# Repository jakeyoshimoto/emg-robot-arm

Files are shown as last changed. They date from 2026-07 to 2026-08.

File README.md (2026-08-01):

# emg-robot-arm

A project to build a 6-DOF robotic arm that uses a tripod-mounted
camera to visually locate a ball on a table and autonomously moves to
grab it. Earlier plans to control the gripper via EMG (muscle-signal)
gestures have been dropped in favor of this camera-only approach.

```
emg-robot-arm/
├── README.md
├── requirements.txt
├── arm/           # PlatformIO firmware for the arm's stepper motors
├── CAD/           # CAD/STL files for the arm and gripper
├── vision/        # camera calibration, ball detection, hand tracking
├── integration/   # wires vision output to arm serial commands
├── docs/          # gantt chart / deadlines
└── datasheets/    # reference PDFs
```

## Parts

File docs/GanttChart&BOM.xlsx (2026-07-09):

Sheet: Gantt Chart
EMG-Controlled Robotic Hand & 7-DOF Robotic Arm — 30-Day Project Gantt Chart
Day-by-day schedule, Day 1–Day 30. All parts are pre-purchased and assumed to arrive by Day 7; Gray columns are scheduled rest days (2 every 7). Yellow cells are hard deadlines for a specific component.
 | Hand Subsystem
 | Arm Subsystem
 | Integration
 | Concept/Shared
 | Hard Deadline
 | Rest Day
ID | Task | Start Day | End Day | Duration (days) | 1 | 2 | 3 | 4 | 5 | 6 | 7 | 8 | 9 | 10 | 11 | 12 | 13 | 14 | 15 | 16 | 17 | 18 | 19 | 20 | 21 | 22 | 23 | 24 | 25 | 26 | 27 | 28 | 29 | 30
1.1/2.1 | Requirements + kickoff (gesture set, joint layout, payload target) | 1 | 1 | 1
2.3 | Arm: vision architecture decision | 1 | 1 | 1
1.4 | Hand CAD: fingers, palm, tendon channels | 1 | 2 | 2
1.5 | Hand CAD: forearm sleeve + wrist joint | 2 | 2 | 1
2.4 | Arm CAD: base, 7 links, motor mounts, interface plate | 1 | 4 | 4
2.4a | Cycloidal drive CAD: housing + disc (joints 1-3) | 3 | 4 | 2
DL1 | HARD DEADLINE: Hand + Arm CAD files finalized, ready to print | 4 | 4 | 1
1.6 | Print hand parts (fingers/palm) - first article | 3 | 4 | 2
1.7 | Print hand parts - reprint pass if needed | 5 | 5 | 1
2.5 | Print arm base + 3 proximal links | 4 | 5 | 2
2.5a | Print cycloidal drive housings + discs (3 joints) | 5 | 5 | 1
1.12pre | EMG firmware skeleton: acquisition + filtering (dev against simulated signal) | 1 | 3 | 3
1.13pre | Gesture classification logic (dev against recorded/simulated EMG data) | 3 | 5 | 3
2.11 | Forward/inverse kinematics solver (math only, no hardware needed) | 1 | 3 | 3
2.12 | Trajectory/motion planning logic | 3 | 5 | 3
2.16pre | Path planning algorithm dev (against simulated/sample scenes) | 4 | 5 | 2
DL2 | HARD DEADLINE: All purchased parts received and inventoried | 8 | 8 | 1
2.6 | Print remaining 4 distal links + end-effector plate | 8 | 8 | 1
2.7 | Reprint pass: warped/failed structural & cycloidal parts | 9 | 9 | 1
1.10 | Bench-test EMG sensor module (hardware now in hand) | 8 | 8 | 1
1.8 | Hand mechanical assembly (tendons, bearings, pins) | 9 | 9 | 1
1.9 | Mount servos in forearm housing | 10 | 10 | 1
1.11 | Electrode placement + skin-contact validation | 10 | 10 | 1
1.12 | EMG firmware: integrate with real sensor signal | 11 | 11 | 1
2.9 | Wire 2x CNC shield/A4988 kits + power distribution | 9 | 10 | 2
2.8 | Arm mechanical assembly incl. cycloidal stage install | 11 | 12 | 2
2.10 | Motion controller firmware: homing, position control (real hardware) | 12 | 12 | 1
DL3 | HARD DEADLINE: Hand fully assembled, Arm fully assembled | 12 | 12 | 1
1.14 | EMG calibration routine + UI | 15 | 15 | 1
1.15 | EMG recalibration iterations (electrode drift, cross-talk) | 15 | 16 | 2
1.16 | Integrate classifier output -> servo mapping | 16 | 16 | 1
1.17 | Grasp tuning (grip force, finger sequencing) | 17 | 18 | 2
DL4 | HARD DEADLINE: Hand catches and holds ball standalone | 18 | 18 | 1
2.13 | Camera calibration, workspace mapping | 15 | 15 | 1
2.14 | Target (ball) detection via OpenCV/MediaPipe | 16 | 17 | 2
2.15 | Obstacle detection + occupancy mapping | 17 | 17 | 1
2.16 | Path planning algorithm with obstacle avoidance (real hardware) | 18 | 19 | 2
2.18 | Integrate vision -> planner -> motion control loop | 18 | 19 | 2
2.18a | Measure cycloidal joint torque vs bare gearbox | 19 | 19 | 1
2.19 | Accuracy + obstacle avoidance tuning | 19 | 19 | 1
DL5 | HARD DEADLINE: Arm reaches target + avoids obstacles standalone | 19 | 19 | 1
3.1 | Mechanical integration: mount hand on arm | 22 | 22 | 1
3.2 | Electrical integration: consolidate harness/power | 22 | 23 | 2
3.3 | Software integration: unify control loop | 23 | 23 | 1
DL6 | HARD DEADLINE: Combined hand+arm software pipeline runs end-to-end (no ball) | 23 | 23 | 1
3.4 | End-to-end dry run (no ball) | 24 | 24 | 1
3.5 | Integration debugging pass | 24 | 25 | 2
DL7 | HARD DEADLINE: Integrated system ready for live-ball trials | 25 | 25 | 1
3.7a | Live trials: full autonomous grasp-and-relocate (round 1) | 26 | 26 | 1
3.7b | Live trials: full autonomous grasp-and-relocate (round 2) | 29 | 29 | 1
3.8 | Rehearsal + contingency prep for final demo | 29 | 29 | 1
DL8 | HARD DEADLINE: Final demonstration | 30 | 30 | 1
3.10 | FINAL DEMONSTRATION | 30 | 30 | 1

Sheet: BOM
EMG-Controlled Robotic Hand
Item | Qty | Cost | Total Cost | Purpose | Source | Progress
EMG Module | 1 | $18.87 | $18.87 | Muscle Contraction Detection | Amazon (https://www.amazon.com/gp/product/B0DQXTVHVX/ref=ox_sc_act_title_1?smid=A1FTIC6G3UW3VA&psc=1) | Not Purchased
EMG Patches 100x | 1 | $17.05 | $17.05 | EMG Replacement Patches | Amazon (https://a.co/d/07yVu8p0) | Not Purchased
MG90S Metal Gear 180 degree Micro Servo 8x | 1 | $18.99 | $18.99 | Finger Articulation Closed | Amazon (https://a.co/d/0gxD0TTA) | Not Purchased
Fishing Line | 1 | $0.00 | $0.00 | Finger Ligaments | Home | Not Purchased
Torsion Spring 10x | 1 | $5.72 | $5.72 | Finger Articulation Open | Amazon (https://a.co/d/030Xd55T) | Not Purchased
Screws, nuts, bolts, misc | 1 | $0.00 | $0.00 | Fixture and Assembly | Home | Not Purchased
PLA filament | 1 | $0.00 | $0.00 | Raw Material | Home | Not Purchased
uxcell 688ZZ Ball Bearing 8x16x5mm (20-pack) | 1 | $8.99 | $8.99 | Finger Joint Bearings | Amazon (https://www.amazon.com/uxcell-Bearing-Shielded-2080088-Bearings/dp/B07FW2YKL8) | Not Purchased
Hand Subtotal |  | $69.62
7-DOF Intelligent Robotic Arm
Item | Qty | Cost |  | Purpose | Source | Progress
FREENOVE Basic Starter Kit for ESP32-S3 | 2 | $25.56 | $51.12 | Microcontroller for Motor Control + Vision Interface | Amazon (https://a.co/d/04XNQ9UA) | Not Purchased
10Pack Nema 17 Stepper Motor | 1 | $66.14 | $66.14 | Arm Joint Actuation | Amazon (https://a.co/d/076g9hVv) | Not Purchased
ACEIRMC 3D Printer CNC Shield V3 + A4988 Driver | 2 | $9.99 | $19.98 | Motor Driver (1 packs = 5 drivers) | Amazon (https://a.co/d/08AV3k6i) | Not Purchased
NICE-POWER DC Power Supply Variable 30V 10A | 1 | $44.99 | $44.99 | Driver/Motor Power Supply | Amazon (https://www.amazon.com/NICE-POWER-Adjustable-Switching-Regulated-Adjustments/dp/B0CDW12H3X) | Not Purchased
HiLetgo KW12-3 Micro Limit Switch (10-Pack) | 1 | $7.99 | $7.99 | Joint Homing Reference (7 needed) | Amazon (https://www.amazon.com/HiLetgo-KW12-3-Roller-Switch-Normally/dp/B07X142VGC) | Not Purchased
uxcell 10 Pcs 6807ZZ Deep Groove Ball Bearings, 35 x 47 x 7mm | 1 | $14.79 | $14.79 | Ball bearing output side | Amazon (https://a.co/d/01JxlTTg) | Not Purchased
20Pcs 6703-ZZ Ball Bearing, 17x23x4mm | 1 | $14.94 | $14.94 | Ball bearing input side | Amazon (https://a.co/d/0c2jdGzu) | Not Purchased
uxcell 22mm Latching Emergency Stop Button (NC) | 1 | $8.99 | $8.99 | Manual Motor Power Cutoff | Amazon (https://www.amazon.com/uxcell-Mounting-Latching-Emergency-Button/dp/B07FRYTH3Z) | Not Purchased
ELEGOO 120pc Dupont Jumper Wire Kit | 1 | $6.99 | $6.99 | ESP32 Prototyping + Sensor Wiring | Amazon (https://www.amazon.com/Elegoo-EL-CP-004-Multicolored-Breadboard-arduino/dp/B01EV70C78) | Not Purchased
Screws, nuts, bolts, misc | 1 | $0.00 | $0.00 | Fixture and Assembly | Home | Not Purchased
PLA filament | 1 | $0.00 | $0.00 | Raw Material | Home | Not Purchased
Zip Ties + Electrical Tape | 1 | $8.00 | $8.00 | Cable Management | Home Depot | Not Purchased
Arm Subtotal |  |  | $243.93
Grand Total |  |  | $243.93

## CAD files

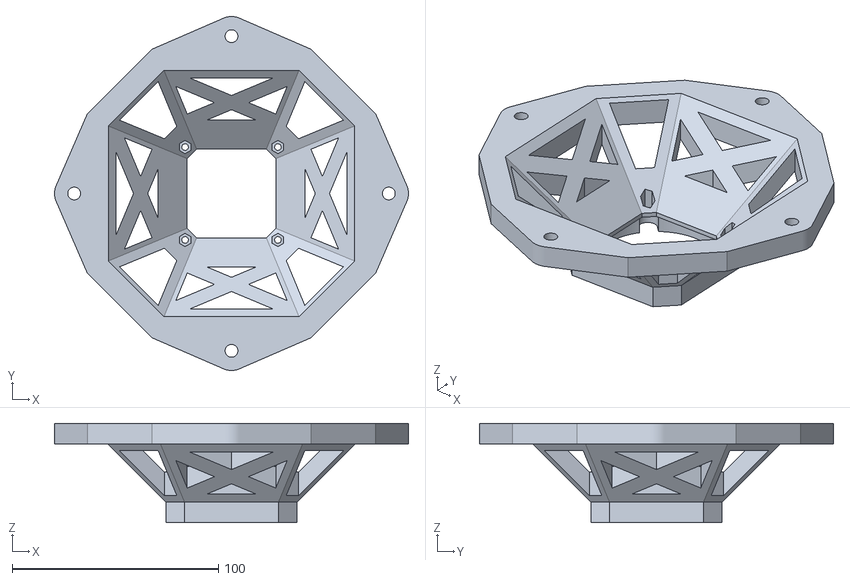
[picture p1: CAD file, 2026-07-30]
CAD/6DoF Arm/Base in mm.stl
171.4 x 171.4 x 48.1

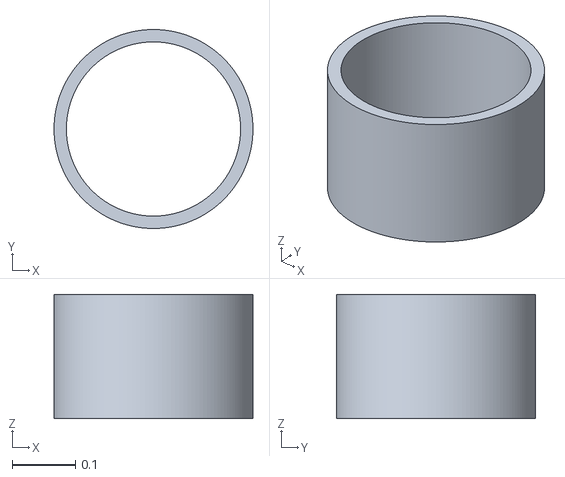
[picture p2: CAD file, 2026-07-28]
CAD/Cycloidal Drive Gearbox/CDG V2 - spacer v2.stl
0.315 x 0.315 x 0.197

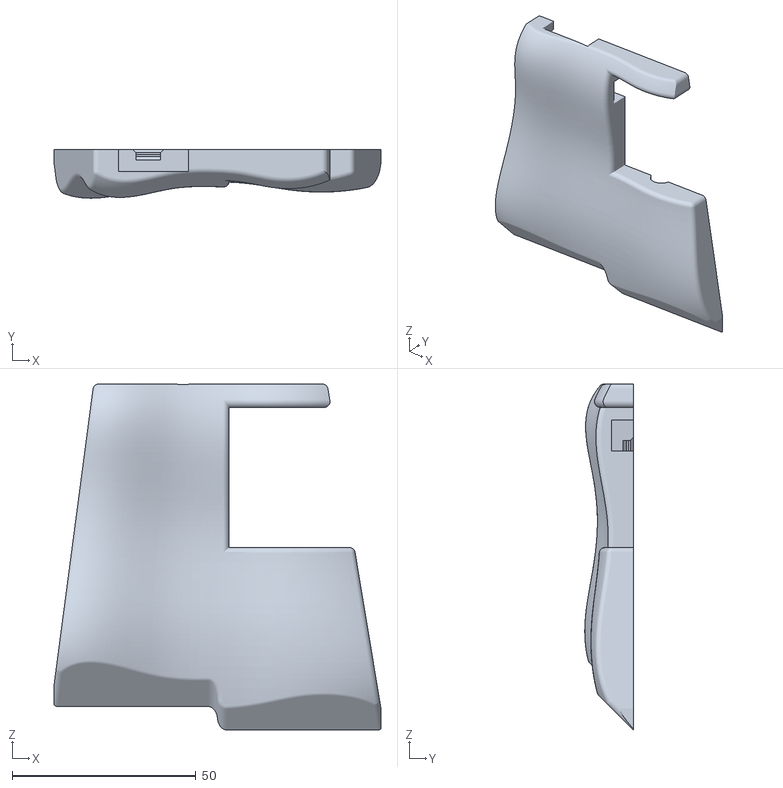
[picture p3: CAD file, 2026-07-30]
CAD/Hand/palm bot no thumb v9 real.stl
88.9 x 13.2 x 94.1

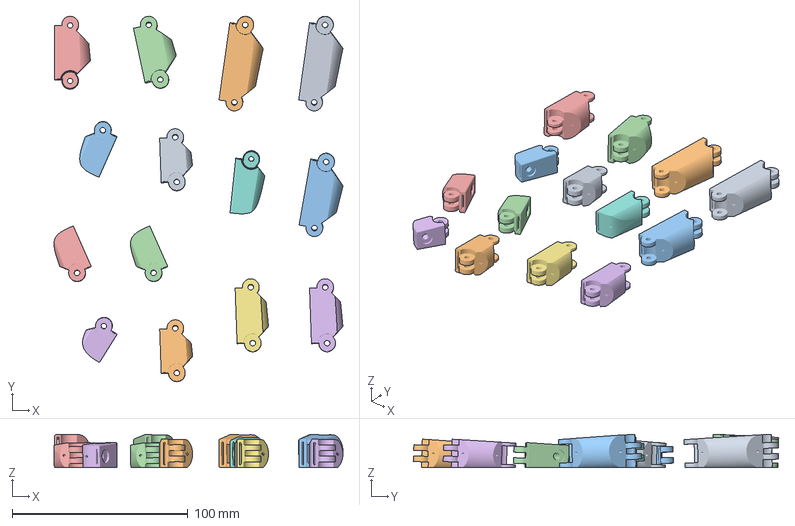
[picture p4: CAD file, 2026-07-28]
CAD/v6/robot_hand_fingers_v7.3mf
164.4 x 208.0 x 19.0 mm
Middle_Ring mcp v6.STL x 2
Index mcp v6.STL
Pinky mcp v6.STL
thumb base v1.STL
Middle_Ring pip v6.STL x 2
thumb tip v1.STL
Pinky pip v6.STL
Index pip v6.STL
Index dip v6.STL
Middle_Ring dip v6.STL x 2
Pinky dip v6.STL

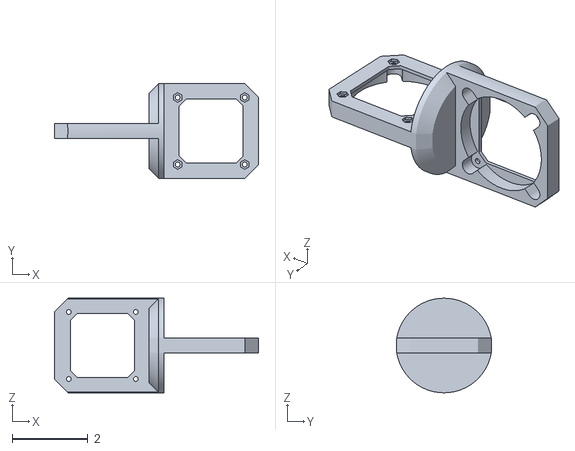
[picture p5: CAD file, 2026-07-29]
CAD/6DoF Arm/Joint 3-4 Mount.stl
5.39 x 2.50 x 2.50

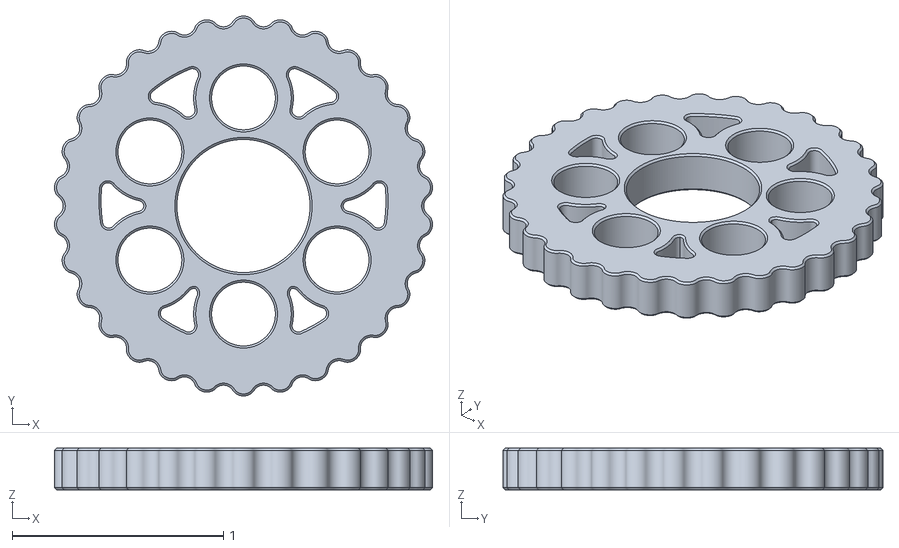
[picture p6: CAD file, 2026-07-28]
CAD/Cycloidal Drive Gearbox/CDG V2 - Cycloidal Disk B.stl
1.79 x 1.80 x 0.197

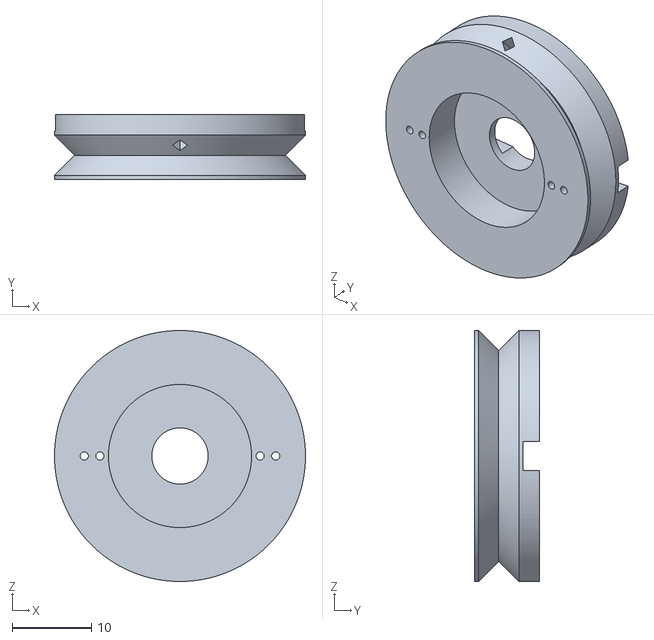
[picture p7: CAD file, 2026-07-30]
CAD/Hand/Pulley v4.stl
31.8 x 8.25 x 31.8

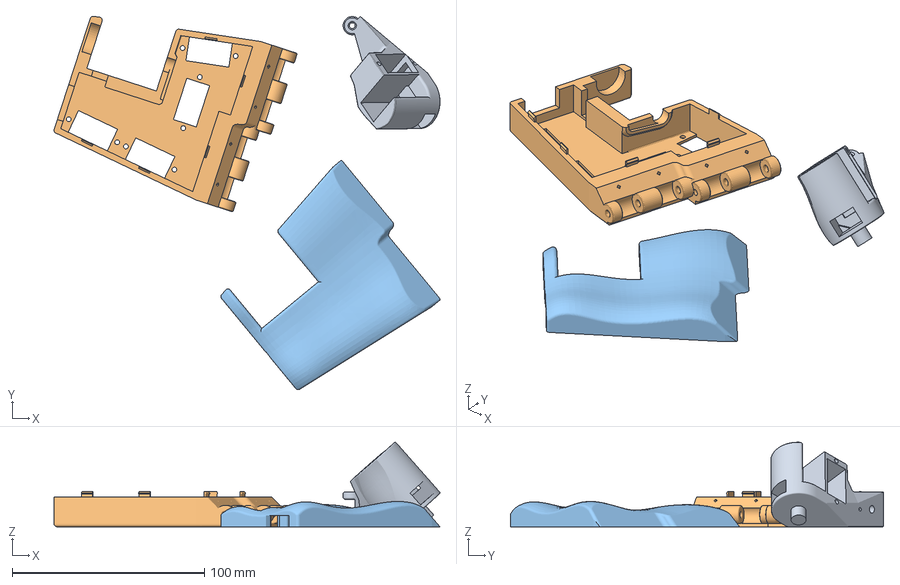
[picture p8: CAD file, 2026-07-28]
CAD/v6/robot_hand_palm_v7.3mf
201.0 x 194.5 x 44.0 mm
palm thumb v6.stl
palm top no thumb v7.STL
palm bot no thumb v7.STL

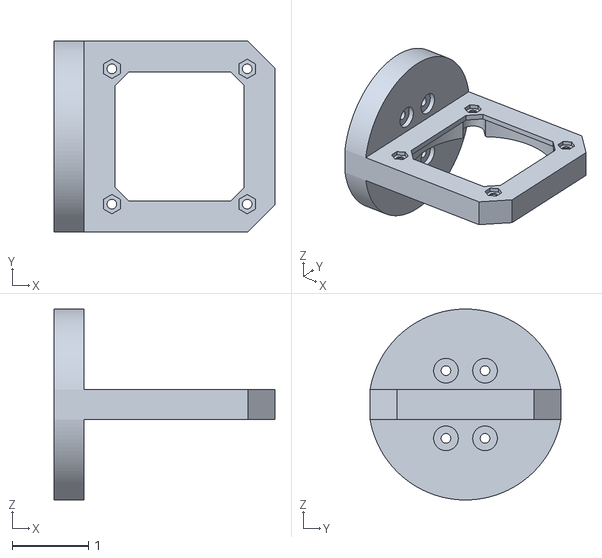
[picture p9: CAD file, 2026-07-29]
CAD/6DoF Arm/Joint 4-5 Mount.stl
2.89 x 2.50 x 2.50

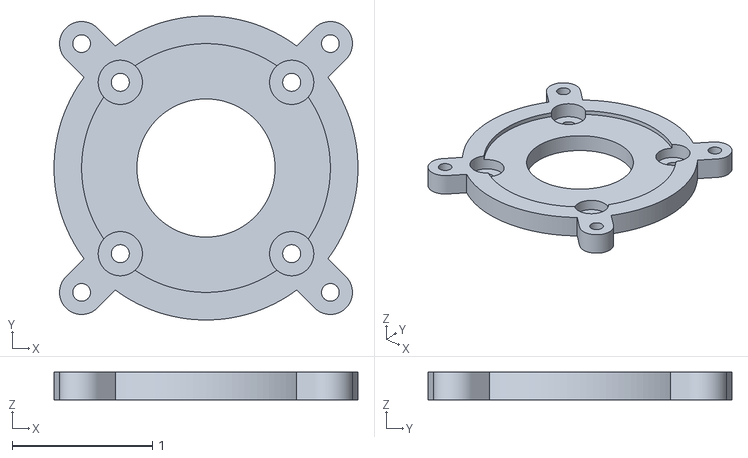
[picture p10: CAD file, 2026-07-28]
CAD/Cycloidal Drive Gearbox/CDG V2 - Motor Plate.stl
2.17 x 2.17 x 0.197

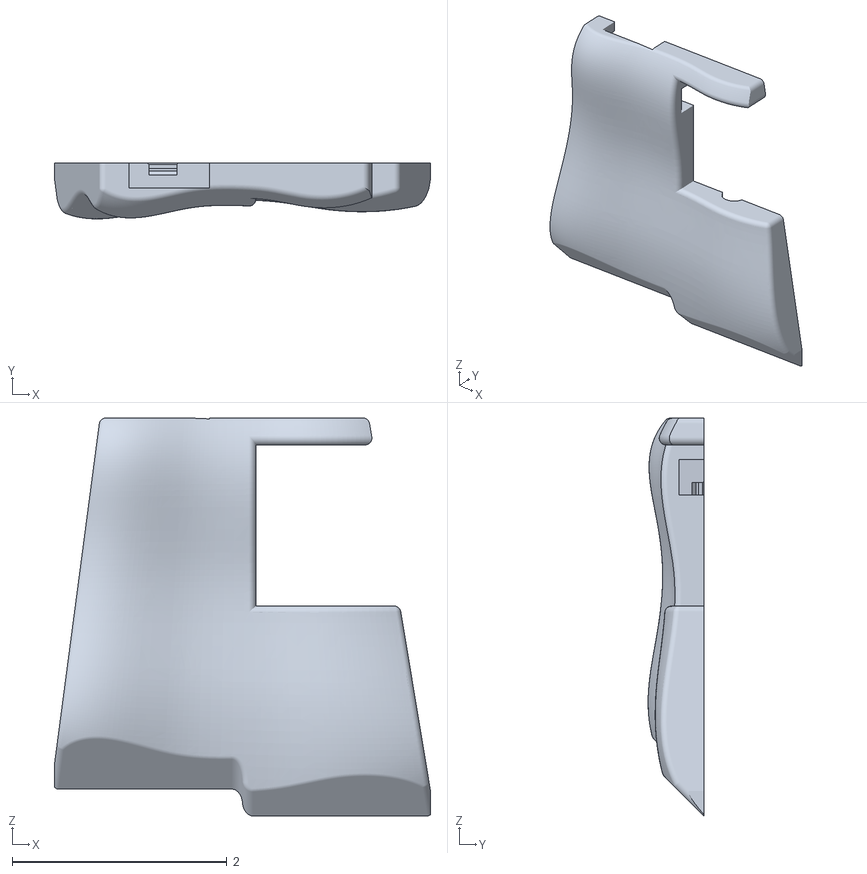
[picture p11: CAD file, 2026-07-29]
CAD/Hand/Palm Bot No Thumb v8.stl
3.50 x 0.519 x 3.70

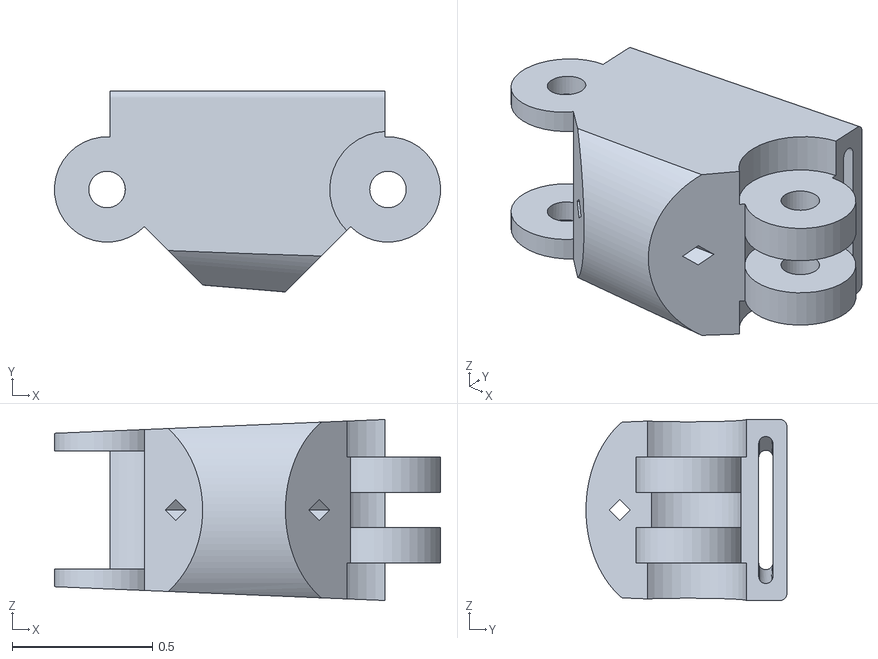
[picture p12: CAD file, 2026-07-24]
CAD/v6/Pinky pip v6.STL
1.37 x 0.716 x 0.645

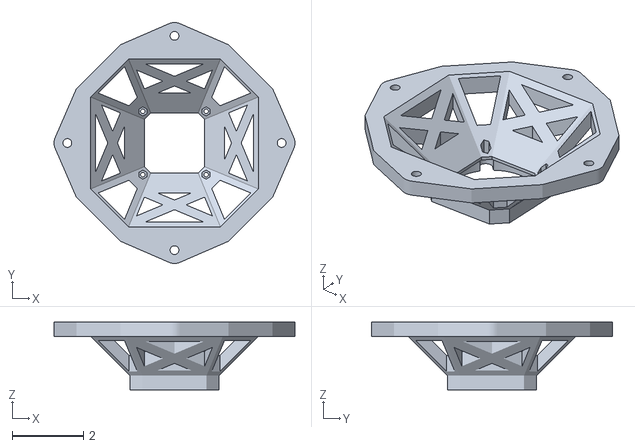
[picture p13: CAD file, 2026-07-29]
CAD/6DoF Arm/Base Mount.stl
6.75 x 6.75 x 1.89

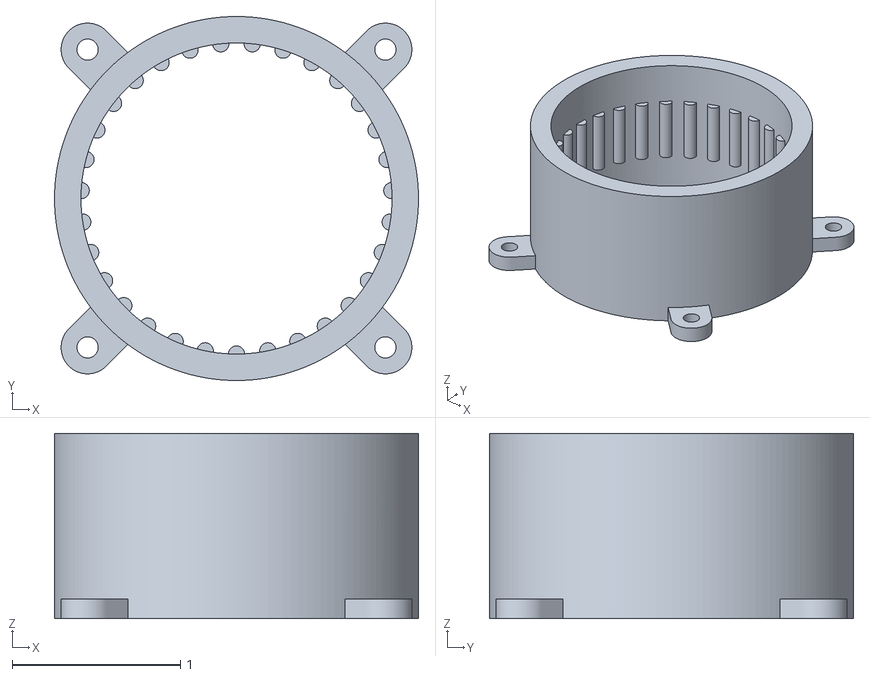
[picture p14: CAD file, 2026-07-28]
CAD/Cycloidal Drive Gearbox/CDG V2 - Ring Gear.stl
2.17 x 2.17 x 1.10

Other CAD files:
CAD/v6/Index mcp v6.STL
CAD/6DoF Arm/Arm 1.stl
CAD/Cycloidal Drive Gearbox/CDG V2 - Bottom Plate.stl
CAD/v6/Middle_Ring dip v6.STL
CAD/6DoF Arm/Arm 2.stl
CAD/6DoF Arm/Hand Joint Mount.stl
CAD/Cycloidal Drive Gearbox/CDG V2 - Cycloidal Disk T.stl
CAD/Cycloidal Drive Gearbox/CDG V2 - Input Shaft T.stl
CAD/Cycloidal Drive Gearbox/CDG V2 - Top Plate.stl
CAD/v5/index dip final (2).STL
CAD/v5/index mcp final (2).STL
CAD/v5/index pip final (2).STL
CAD/v5/middle_ring dip final (2).STL
CAD/v5/middle_ring mcp final (2).STL
CAD/v5/middle_ring pip final (2).STL
CAD/v5/palm thumb v5.STL
CAD/v5/palm v5 no thumb.3mf
CAD/v5/palm v5 no thumb.STL
CAD/v5/pinky dip final (2).STL
CAD/v5/pinky mcp final (2).STL
CAD/v5/pinky pip final (2).STL
CAD/v5/pulley v4 1.25in.stl
CAD/v5/pulley v4 1in.stl
CAD/v5/thumb base v1.STL
CAD/v5/thumb tip v1.STL
CAD/v6/Index dip v6.STL
CAD/v6/Index pip v6.STL
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

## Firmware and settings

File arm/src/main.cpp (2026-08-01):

// Stepper + servo bring-up firmware for the 6-DOF arm.
// Drives NEMA17/A4988 stepper axes and 5 gripper/hand servos over serial.
// Servos run through a PCA9685 I2C PWM driver board. Also reads a
// single-channel analog EMG sensor on GPIO5 for bring-up testing (legacy,
// unused now that the project has moved to camera-guided control). No
// limit switches or homing yet, so each axis is soft-capped in firmware
// to one full output/joint rotation (accounting for gear ratio) in either
// direction from wherever it powered on - see maxAxisSteps().
//
// Serial commands, 115200 baud:
//   m<axis> <steps>      move one motor a relative number of steps, e.g. m0 200
//                         (clamped to +/-1 output rev from power-on position:
//                         +/-6000 steps on the geared axes 0-4, +/-200 on
//                         axis 5, the direct-drive hand)
//   speed m<axis> <v>    set that motor's max speed in steps/sec
//   stop                 stop all motors immediately
//   s<ch> <angle>        move one servo channel to an absolute angle, 0-180
//   emg                  toggle streaming raw EMG readings ("emg <0-4095>")
//   ?                    show this again

#include <Arduino.h>
#include <AccelStepper.h>
#include <Wire.h>
#include <Adafruit_PWMServoDriver.h>

constexpr int NUM_AXES = 6;

struct AxisPins {
  uint8_t step;
  uint8_t dir;
};

// Stepper configuration - one STEP/DIR pair per joint
const AxisPins AXIS_PINS[NUM_AXES] = {
  {1, 2},
  {42, 41},
  {40, 39},
  {38, 37},
  {36, 35},
  {48, 47},
};

constexpr float DEFAULT_MAX_SPEED = 500.0;     // steps/sec, conservative for first bring-up
constexpr float DEFAULT_ACCELERATION = 250.0;  // steps/sec^2

// Motor/gearbox configuration. Every motor is 200 full steps/rev (1.8
// deg/step, no microstepping) at its own shaft. Axes 0-4 drive their joint
// through a 30:1 cycloidal gearbox, so it takes 200*30 = 6000 motor steps
// for one output/joint rotation; axis 5 (the hand) is direct-drive with no
// gearbox, so 200 motor steps is one output rotation there.
constexpr int STEPS_PER_MOTOR_REV = 200;
const int GEAR_RATIO[NUM_AXES] = {30, 30, 30, 30, 30, 1};

// No limit switches or homing yet, so as a stand-in safety limit, cap each
// axis to one full *output/joint* rotation (accounting for that axis's
// gear ratio) in either direction from wherever it happened to power on.
long maxAxisSteps(int axis) {
  return (long)STEPS_PER_MOTOR_REV * GEAR_RATIO[axis];
}

AccelStepper axes[NUM_AXES] = {
  AccelStepper(AccelStepper::DRIVER, AXIS_PINS[0].step, AXIS_PINS[0].dir),
  AccelStepper(AccelStepper::DRIVER, AXIS_PINS[1].step, AXIS_PINS[1].dir),
  AccelStepper(AccelStepper::DRIVER, AXIS_PINS[2].step, AXIS_PINS[2].dir),
  AccelStepper(AccelStepper::DRIVER, AXIS_PINS[3].step, AXIS_PINS[3].dir),
  AccelStepper(AccelStepper::DRIVER, AXIS_PINS[4].step, AXIS_PINS[4].dir),
  AccelStepper(AccelStepper::DRIVER, AXIS_PINS[5].step, AXIS_PINS[5].dir),
};

// Servo configuration - PCA9685 over I2C, default address 0x40
constexpr int I2C_SDA_PIN = 21;
constexpr int I2C_SCL_PIN = 45;  // strapping pin, only sampled at boot
constexpr int NUM_SERVOS = 6;
constexpr int SERVO_MIN_ANGLE = 0;
constexpr int SERVO_MAX_ANGLE = 180;
constexpr int SERVO_MIN_PULSE_US = 500;
constexpr int SERVO_MAX_PULSE_US = 2400;
constexpr float PWM_FREQ_HZ = 50.0;

Adafruit_PWMServoDriver pwm = Adafruit_PWMServoDriver();

// EMG sensor (Advancer Technologies Muscle Sensor v3 or clone) - needs
// a dual +Vs/-Vs supply (e.g. two 9V batteries, center tap = GND), and
// its SIG output swings 0-Vs, so it goes through an external resistor
// divider (SIG -> 20k -> node -> 10k -> GND, node -> GPIO5) to land
// within the ADC's 0-3.3V range before reaching this pin. GPIO5 is
// ADC1_CH4, free and not shared with any stepper/I2C pin above.
constexpr int EMG_PIN = 5;
constexpr unsigned long EMG_SAMPLE_INTERVAL_MS = 20;  // ~50 Hz

bool emgStreaming = false;
unsigned long lastEmgSampleMs = 0;

uint16_t angleToTicks(int angle) {
  long pulseUs = map(angle, 0, 180, SERVO_MIN_PULSE_US, SERVO_MAX_PULSE_US);
  return (uint16_t)((pulseUs * 4096L) / (long)(1000000.0 / PWM_FREQ_HZ));
}

void printHelp() {
  Serial.println();
  Serial.println("Commands:");
  Serial.println("  m<axis> <steps>    move one motor a relative number of steps, e.g. m0 200");
  Serial.println("                     (clamped to +/-1 output rev from power-on: +/-6000 steps");
  Serial.println("                     on geared axes 0-4, +/-200 on axis 5 the direct-drive hand)");
  Serial.println("  speed m<axis> <v>  set that motor's max speed in steps/sec");
  Serial.println("  stop               stop all motors immediately");
  Serial.println("  s<ch> <angle>      move one servo channel to an absolute angle, 0-180");
  Serial.println("  emg                toggle streaming raw EMG readings (\"emg <0-4095>\")");
  Serial.println("  ?                  show this again");
}

void handleCommand(String line) {
  line.trim();
  if (line.length() == 0) {
    return;
  }

  if (line == "?") {
    printHelp();
    return;
  }

  if (line == "stop") {
    for (int i = 0; i < NUM_AXES; i++) {
      axes[i].stop();
    }
    Serial.println("Stopped all motors.");
    return;
  }

  if (line.startsWith("speed ")) {
    int axis, value;
    if (sscanf(line.c_str(), "speed m%d %d", &axis, &value) == 2 &&
        axis >= 0 && axis < NUM_AXES) {
      axes[axis].setMaxSpeed((float)value);
      Serial.printf("Motor %d max speed set to %d steps/sec.\n", axis, value);
    } else {
      Serial.println("Usage: speed m<axis> <steps/sec>");
    }
    return;
  }

  if (line.startsWith("m")) {
    int axis, steps;
    if (sscanf(line.c_str(), "m%d %d", &axis, &steps) == 2 &&
        axis >= 0 && axis < NUM_AXES) {
      long limit = maxAxisSteps(axis);
      long target = axes[axis].currentPosition() + (long)steps;
      long clampedTarget = constrain(target, -limit, limit);
      if (clampedTarget != target) {
        Serial.printf("Motor %d move clamped to stay within +/-%ld steps (1 output rev) of power-on position.\n",
                      axis, limit);
      }
      axes[axis].moveTo(clampedTarget);
      Serial.printf("Motor %d moving to %ld steps from power-on.\n", axis, clampedTarget);
    } else {
      Serial.printf("Usage: m<axis 0-%d> <steps>\n", NUM_AXES - 1);
    }
    return;
  }

  if (line == "emg") {
    emgStreaming = !emgStreaming;
    Serial.println(emgStreaming ? "EMG streaming on." : "EMG streaming off.");
    return;
  }

  if (line.startsWith("s")) {
    int channel, angle;
    if (sscanf(line.c_str(), "s%d %d", &channel, &angle) == 2 &&
        channel >= 0 && channel < NUM_SERVOS &&
        angle >= SERVO_MIN_ANGLE && angle <= SERVO_MAX_ANGLE) {
      pwm.setPWM(channel, 0, angleToTicks(angle));
      Serial.printf("Servo %d moving to %d degrees.\n", channel, angle);
    } else {
      Serial.printf("Usage: s<channel 0-%d> <angle %d-%d>\n",
                     NUM_SERVOS - 1, SERVO_MIN_ANGLE, SERVO_MAX_ANGLE);
    }
    return;
  }

  Serial.println("Unrecognized command, type ? for help.");
}

void setup() {
  Serial.begin(115200);
  while (!Serial) {
    // wait for USB serial to come up on boards where this matters
  }

  for (int i = 0; i < NUM_AXES; i++) {
    axes[i].setMaxSpeed(DEFAULT_MAX_SPEED);
    axes[i].setAcceleration(DEFAULT_ACCELERATION);
  }

  Wire.begin(I2C_SDA_PIN, I2C_SCL_PIN);
  pwm.begin();
  pwm.setPWMFreq(PWM_FREQ_HZ);

  pinMode(EMG_PIN, INPUT);
  analogReadResolution(12);                     // 0-4095 across 0-3.3V
  analogSetPinAttenuation(EMG_PIN, ADC_11db);    // full 0-3.3V input range

  Serial.println("Stepper + servo bring-up firmware ready.");
  printHelp();
}

void loop() {
  if (Serial.available()) {
    String line = Serial.readStringUntil('\n');
    handleCommand(line);
  }

  for (int i = 0; i < NUM_AXES; i++) {
    axes[i].run();
  }

  if (emgStreaming && millis() - lastEmgSampleMs >= EMG_SAMPLE_INTERVAL_MS) {
    lastEmgSampleMs = millis();
    Serial.printf("emg %d\n", analogRead(EMG_PIN));
  }
}

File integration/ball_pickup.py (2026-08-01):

"""
Finds the ball via vision/ball_detection.py and drives the arm's base
axis (axis 0, horizontal) and axis 2 (vertical - axis 1 is skipped, not
used for this) until the ball is centered in frame on both axes. This is
a first, deliberately narrow step toward a full pick-up sequence: it only
aims, doesn't reach or grab yet.

How a pixel offset becomes a step count:
    Each axis's pixel offset from its frame-center axis (horizontal
    offset from the vertical center line for axis 0, vertical offset
    from the horizontal center line for axis 2) is multiplied by that
    axis's hand-tunable gain (STEPS_PER_PIXEL / Y_STEPS_PER_PIXEL, not
    derived from camera calibration, since none has been run yet - see
    vision/camera_calibration.py) and direction sign (BASE_DIRECTION /
    Y_DIRECTION). Both axes sit behind the same 30:1 cycloidal gearbox
    (see GEAR_RATIO in arm/src/main.cpp). Y_DIRECTION hasn't been
    confirmed against real hardware yet (BASE_DIRECTION was, the hard
    way) - expect to flip it once tested.

Usage:
    python integration/ball_pickup.py --list-ports
    python integration/ball_pickup.py --port COM4
    python integration/ball_pickup.py --dry-run   # detect + print, don't move the arm

Shows a live camera view with the detected ball circled and reference
lines through the frame's horizontal and vertical center. Press SPACE to
start a centering run: on every camera frame it re-measures the ball's
offset on both axes and sends fresh corrections (or just prints them,
under --dry-run) proportional to those offsets - so the commanded move
shrinks, and the arm naturally slows down, on each axis independently as
it gets closer to centered, rather than one big jump that has to be
corrected afterward. It stops issuing moves once the ball holds within
CENTER_TOLERANCE_PX of center on both axes for STABLE_FRAMES_REQUIRED
frames in a row (debounced so one lucky/noisy frame doesn't end it
early), or after MAX_CENTERING_SECONDS if it never gets there. Only if it
actually settled (not on a timeout) does it then estimate distance to the
ball from its apparent radius (similar-triangles, see compute_distance_cm())
and print it, before going back to waiting for the next SPACE press.
Press 'q' any time
(including mid-run) or close the window to quit.
"""

import argparse
import os
import sys
import time

import cv2
import numpy as np
import serial
from serial.tools import list_ports

REPO_ROOT = os.path.dirname(os.path.dirname(os.path.abspath(__file__)))
sys.path.insert(0, REPO_ROOT)
from vision import ball_detection as bd  # noqa: E402  (needs REPO_ROOT on sys.path first)

BAUD_RATE = 115200

BASE_AXIS = 0              # axis 0 = base rotation (horizontal), see AXIS_PINS in arm/src/main.cpp
Y_AXIS = 2                 # axis 2 = vertical tilt; axis 1 is skipped, not used for this
STEPS_PER_MOTOR_REV = 200  # matches STEPS_PER_MOTOR_REV in arm/src/main.cpp
BASE_GEAR_RATIO = 30       # matches GEAR_RATIO[0] in arm/src/main.cpp
Y_GEAR_RATIO = 30          # matches GEAR_RATIO[2] in arm/src/main.cpp - same 30:1 as the base axis

# Hand-tunable proportional gains: motor steps per pixel of offset from
# frame center, one per axis since they may need different tuning.
# STEPS_PER_PIXEL was bumped up from an original 2.0 (too weak a turn on
# real hardware); Y_STEPS_PER_PIXEL just starts at that same value since
# it hasn't been tuned against real hardware yet either.
STEPS_PER_PIXEL = 6.0
Y_STEPS_PER_PIXEL = 6.0

# Flip to -1 if a positive offset (ball right of frame center / below
# frame center) ends up moving that axis the wrong way on real hardware.
# BASE_DIRECTION was confirmed on real hardware (+1 was backwards, hence
# -1 here); Y_DIRECTION is still an unverified guess - expect to flip it
# once tested.
BASE_DIRECTION = -1
Y_DIRECTION = 1

# The firmware clamps every axis to +/-1 output/joint rotation from
# wherever it powered on, as a stand-in for limit switches/homing - see
# maxAxisSteps() in arm/src/main.cpp. Both these axes sit behind a 30:1
# gearbox, so that's 6000 motor steps, not 200. Mirrored here so we can
# warn instead of silently sending a move that gets truncated.
MAX_BASE_AXIS_STEPS = STEPS_PER_MOTOR_REV * BASE_GEAR_RATIO
MAX_Y_AXIS_STEPS = STEPS_PER_MOTOR_REV * Y_GEAR_RATIO

# How close to frame-center counts as "centered" and stops the run. Ball
# radius is usually 15-40px at typical distances, so this is intentionally
# a bit loose rather than chasing exact pixel alignment.
CENTER_TOLERANCE_PX = 15

# Consecutive under-tolerance frames required before declaring "centered"
# and stopping, so a single noisy/lucky frame doesn't end the run early.
STABLE_FRAMES_REQUIRED = 3

# Minimum time between sent correction commands during a centering run.
# Short enough to feel continuous (re-targets several times a second as
# new frames come in) without flooding the serial link/motor with a new
# command on literally every camera frame.
CORRECTION_INTERVAL_SECONDS = 0.15

# Safety cap on how long a single centering run is allowed to keep
# correcting, in case it never converges (persistent detection noise, an
# overshooting gain, oscillation, etc).
MAX_CENTERING_SECONDS = 20.0

# Dynamic speed control, using the firmware's existing "speed m<axis> <v>"
# command. A proportional step count alone doesn't actually slow the arm
# down as it approaches: AccelStepper accelerates up to whatever max speed
# is set and cruises there for as long as the target keeps getting
# extended (which it does every tick while offset is still large), so it
# was cruising at the firmware's DEFAULT_MAX_SPEED (500 steps/sec, see
# arm/src/main.cpp) right up until nearly the end. Instead, explicitly cap
# and taper the speed itself: far from center it moves at
# MAX_SPEED_STEPS_PER_SEC (already well under the firmware default), and
# within SPEED_TAPER_RANGE_PX of center that tapers linearly down to
# MIN_SPEED_STEPS_PER_SEC.
FIRMWARE_DEFAULT_MAX_SPEED = 500  # matches DEFAULT_MAX_SPEED in arm/src/main.cpp, restored on exit
MAX_SPEED_STEPS_PER_SEC = 150
MIN_SPEED_STEPS_PER_SEC = 20
SPEED_TAPER_RANGE_PX = 150  # offset at/beyond which full MAX_SPEED_STEPS_PER_SEC applies

# Set True if the camera is physically mounted upside down - every frame
# gets rotated 180 degrees before detection/display. This also mirrors
# left/right in pixel space (a 180-degree rotation flips both axes), so
# BASE_DIRECTION was tuned against the unflipped image and may need
# re-checking on real hardware now that this is on.
CAMERA_UPSIDE_DOWN = True
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

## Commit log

2026-07-09 initial commit with some working cv files as well as some basic stepper motor tests
    [GanttChart&BOM.xlsx]
2026-07-12 updated vision tracking for blue nerf ball & basic controls for motors and servos
2026-07-17 initial testing with hand servos completed
2026-07-20 moved stl into seperate folder
    [index dip final (2).STL, index mcp final (2).STL, index pip final (2).STL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]
2026-07-21 hand tracking controlling servos, need to tune thumb a bit more
2026-07-21 reverted to old version of hand tracking
    [hand_control.py]
2026-07-24 attempt at emg reading and adjustments to servo and stepper control
2026-07-28 updates to hand control
    [robot_hand_fingers_v7.3mf, robot_hand_palm_v7.3mf]
2026-07-30 re-organize files
    [index dip final (2).STL, index mcp final (2).STL, index pip final (2).STL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]
2026-08-01 arm adjusts x and y axis to track ball and measures distance in cm
